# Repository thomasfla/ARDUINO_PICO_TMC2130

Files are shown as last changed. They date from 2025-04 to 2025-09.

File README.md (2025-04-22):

# ARDUINO_PICO_TMC2130
Control 3 TMC2130 stepper driver via USB comands (TMX2130 + RP2350 / RP2040)

This is configured to control stepper motors of a bambulab A1 mini.

## Hardware:

* 3x SilentStepStick - TMC2130 Stepper Motor Driver
* 1x Raspberry pi Pico2 dev board

## USB Protocol:

The board will be seen as a virtual COM port.

Send target position, max velocity and max acceleration for all axis (in step, step/s, step/s2)

`X 2000 1000 2000\n`
`Y 500 1000 2000\n` etc..

The driver will send at a chosen period the motor position and velocity:
`X 9030 0 Y 4340 0 Z 0 0`

You can update the target position on the fly. This is usefull for reactive control given other feedback inputs.

## Homing

The code includes a soft homing sequence that as been tuned for Bambulab A1 mini.
This uses stallGuard feature of the tmc2130 drivers.

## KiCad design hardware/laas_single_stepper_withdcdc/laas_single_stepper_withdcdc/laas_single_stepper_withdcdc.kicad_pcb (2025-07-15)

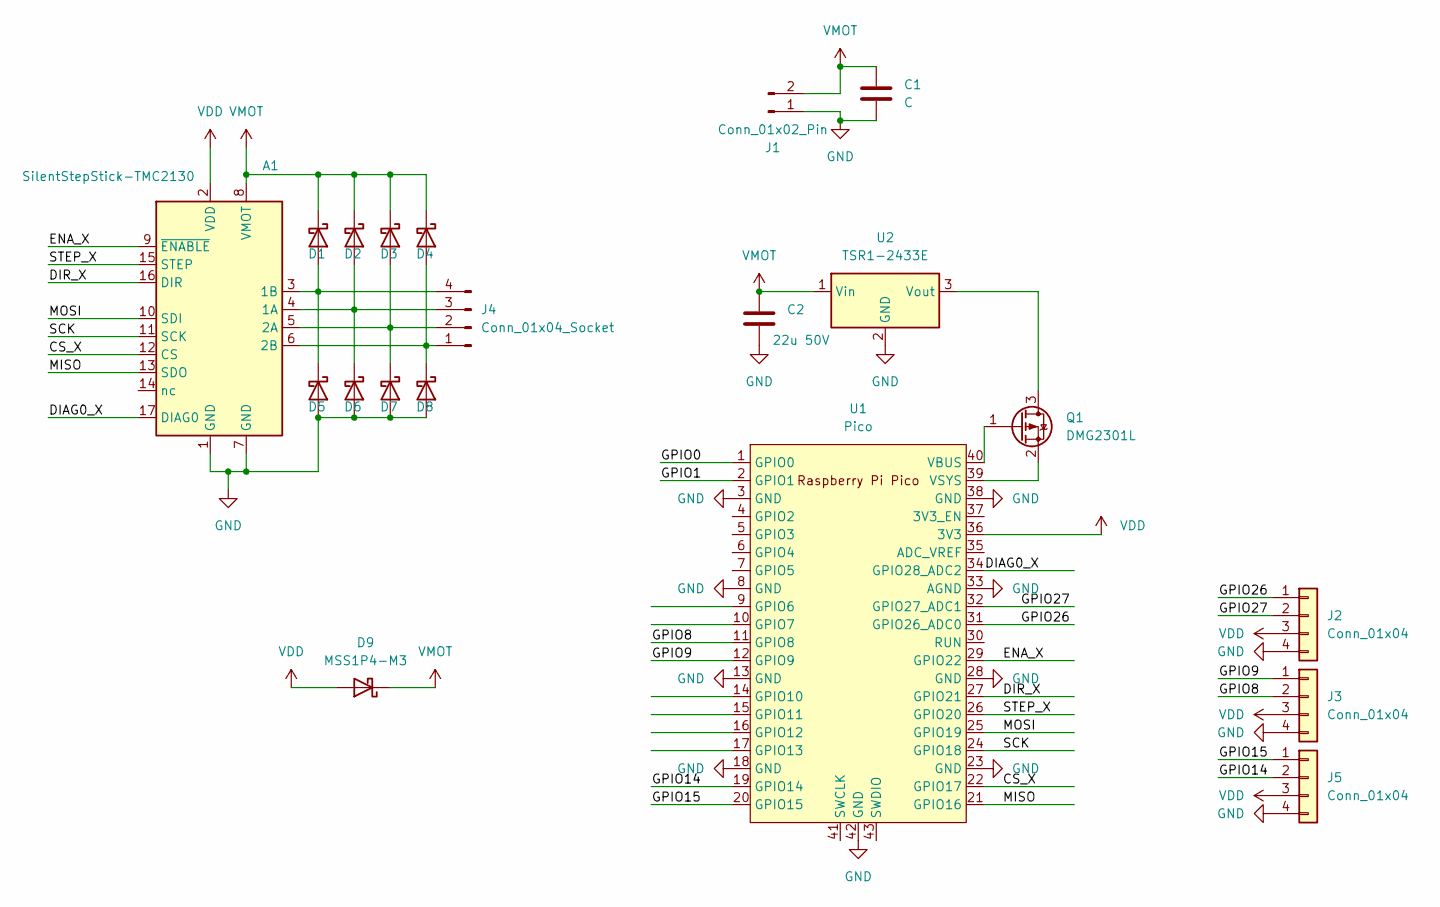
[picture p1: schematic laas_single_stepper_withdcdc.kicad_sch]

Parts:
A1: SilentStepStick-TMC2130; Pololu_Breakout-16_15.2x20.3mm
C1: C; C_1210_3225Metric
C2: 22u 50V; C_1210_3225Metric
D1, D2, D3, D4, D5, D6, D7, D8, D9: MSS1P4-M3; D_MicroSMP_AK
J1: Conn_01x02_Pin; AMASS_XT30PW-M_1x02_P2.50mm_Horizontal
J2, J3, J5: Conn_01x04; NS-Tech_Grove_1x04_P2mm_Vertical
J4: Conn_01x04_Socket; JST_XH_S4B-XH-A_1x04_P2.50mm_Horizontal
Q1: DMG2301L; SOT-23
U1: Pico; RPi_Pico_SMD_TH
U2: TSR1-2433E; Converter_DCDC_TRACO_TSR1-xxxxE_THT

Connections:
/CS_X: A1.12 (CS), U1.22 (GPIO17)
/DIAG0_X: A1.17 (DIAG0), U1.34 (GPIO28_ADC2)
/DIR_X: A1.16 (DIR), U1.27 (GPIO21)
/ENA_X: A1.9 (~ENABLE), U1.29 (GPIO22)
/GPIO0: U1.1 (GPIO0)
/GPIO1: U1.2 (GPIO1)
/GPIO8: J3.2, U1.11 (GPIO8)
/GPIO9: J3.1, U1.12 (GPIO9)
/GPIO14: J5.2, U1.19 (GPIO14)
/GPIO15: J5.1, U1.20 (GPIO15)
/GPIO26: J2.1, U1.31 (GPIO26_ADC0)
/GPIO27: J2.2, U1.32 (GPIO27_ADC1)
/MISO: A1.13 (SDO), U1.21 (GPIO16)
/MOSI: A1.10 (SDI), U1.25 (GPIO19)
/SCK: A1.11 (SCK), U1.24 (GPIO18)
/STEP_X: A1.15 (STEP), U1.26 (GPIO20)
GND: A1.1 (GND), A1.7 (GND), C1.2, C2.2, D5.2 (A), D6.2 (A), D7.2 (A), D8.2 (A), J1.1, J2.4, J3.4, J5.4, U1.3 (GND), U1.8 (GND), U1.13 (GND), U1.18 (GND), U1.23 (GND), U1.28 (GND), U1.33 (AGND), U1.38 (GND), U1.42 (GND), U2.2 (GND)
unnamed: A1.4 (1A), D2.2 (A), D6.1 (K), J4.3
unnamed: A1.3 (1B), D1.2 (A), D5.1 (K), J4.4
unnamed: A1.5 (2A), D3.2 (A), D7.1 (K), J4.2
unnamed: A1.6 (2B), D4.2 (A), D8.1 (K), J4.1
unnamed: Q1.3 (D), U2.3 (Vout)
unnamed: Q1.1 (G), U1.40 (VBUS)
unnamed: Q1.2 (S), U1.39 (VSYS)
VDD: A1.2 (VDD), D9.2 (A), J2.3, J3.3, J5.3, U1.36 (3V3)
VMOT: A1.8 (VMOT), C1.1, C2.1, D1.1 (K), D2.1 (K), D3.1 (K), D4.1 (K), D9.1 (K), J1.2, U2.1 (Vin)

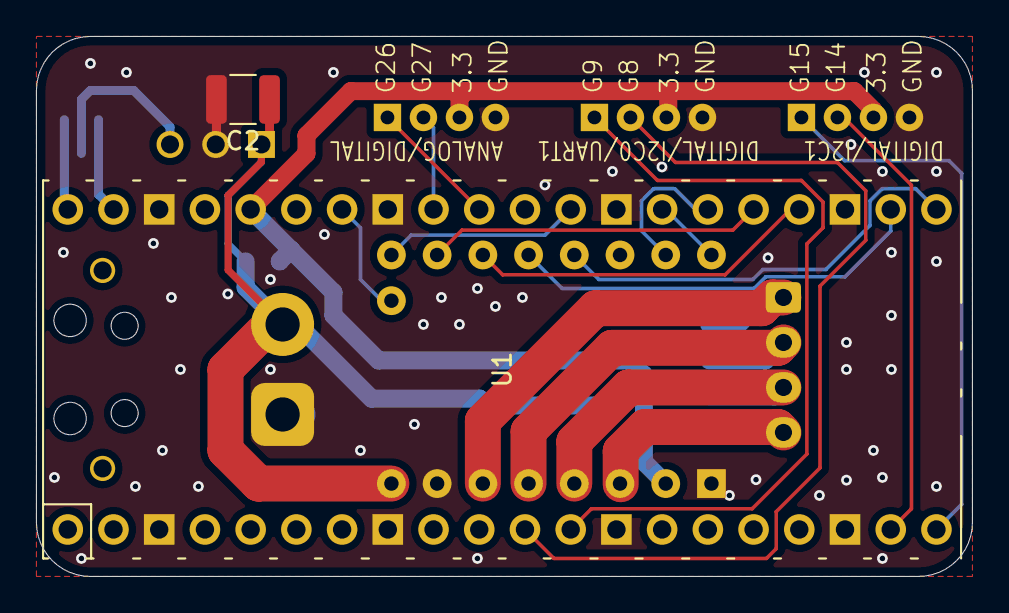
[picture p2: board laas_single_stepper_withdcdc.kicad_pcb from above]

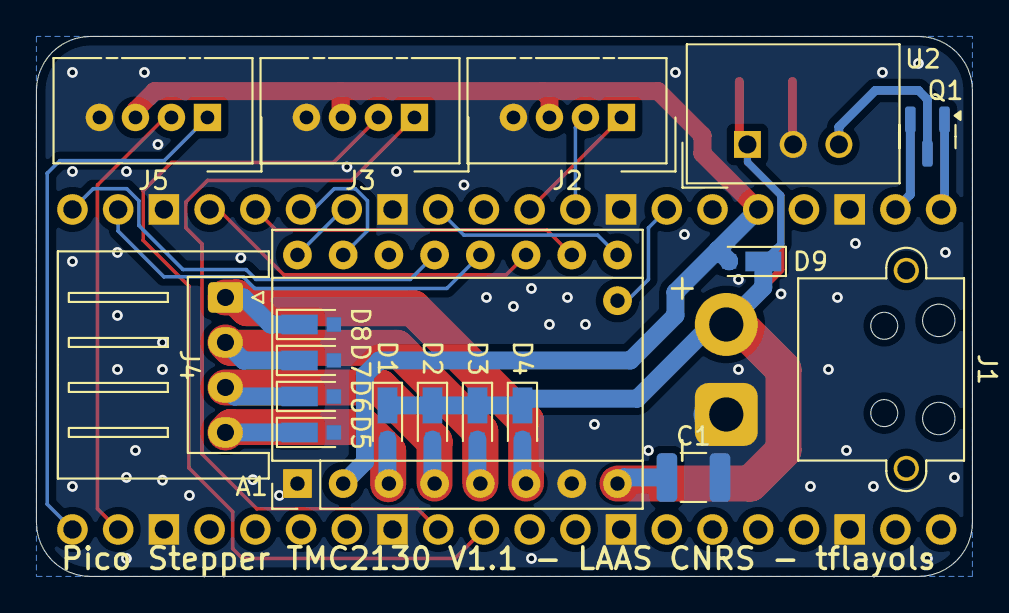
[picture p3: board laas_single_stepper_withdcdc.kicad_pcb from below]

Board: 2 copper layers, 52.0 x 30.0 mm, 20 parts (18 on the bottom side), 24 nets.

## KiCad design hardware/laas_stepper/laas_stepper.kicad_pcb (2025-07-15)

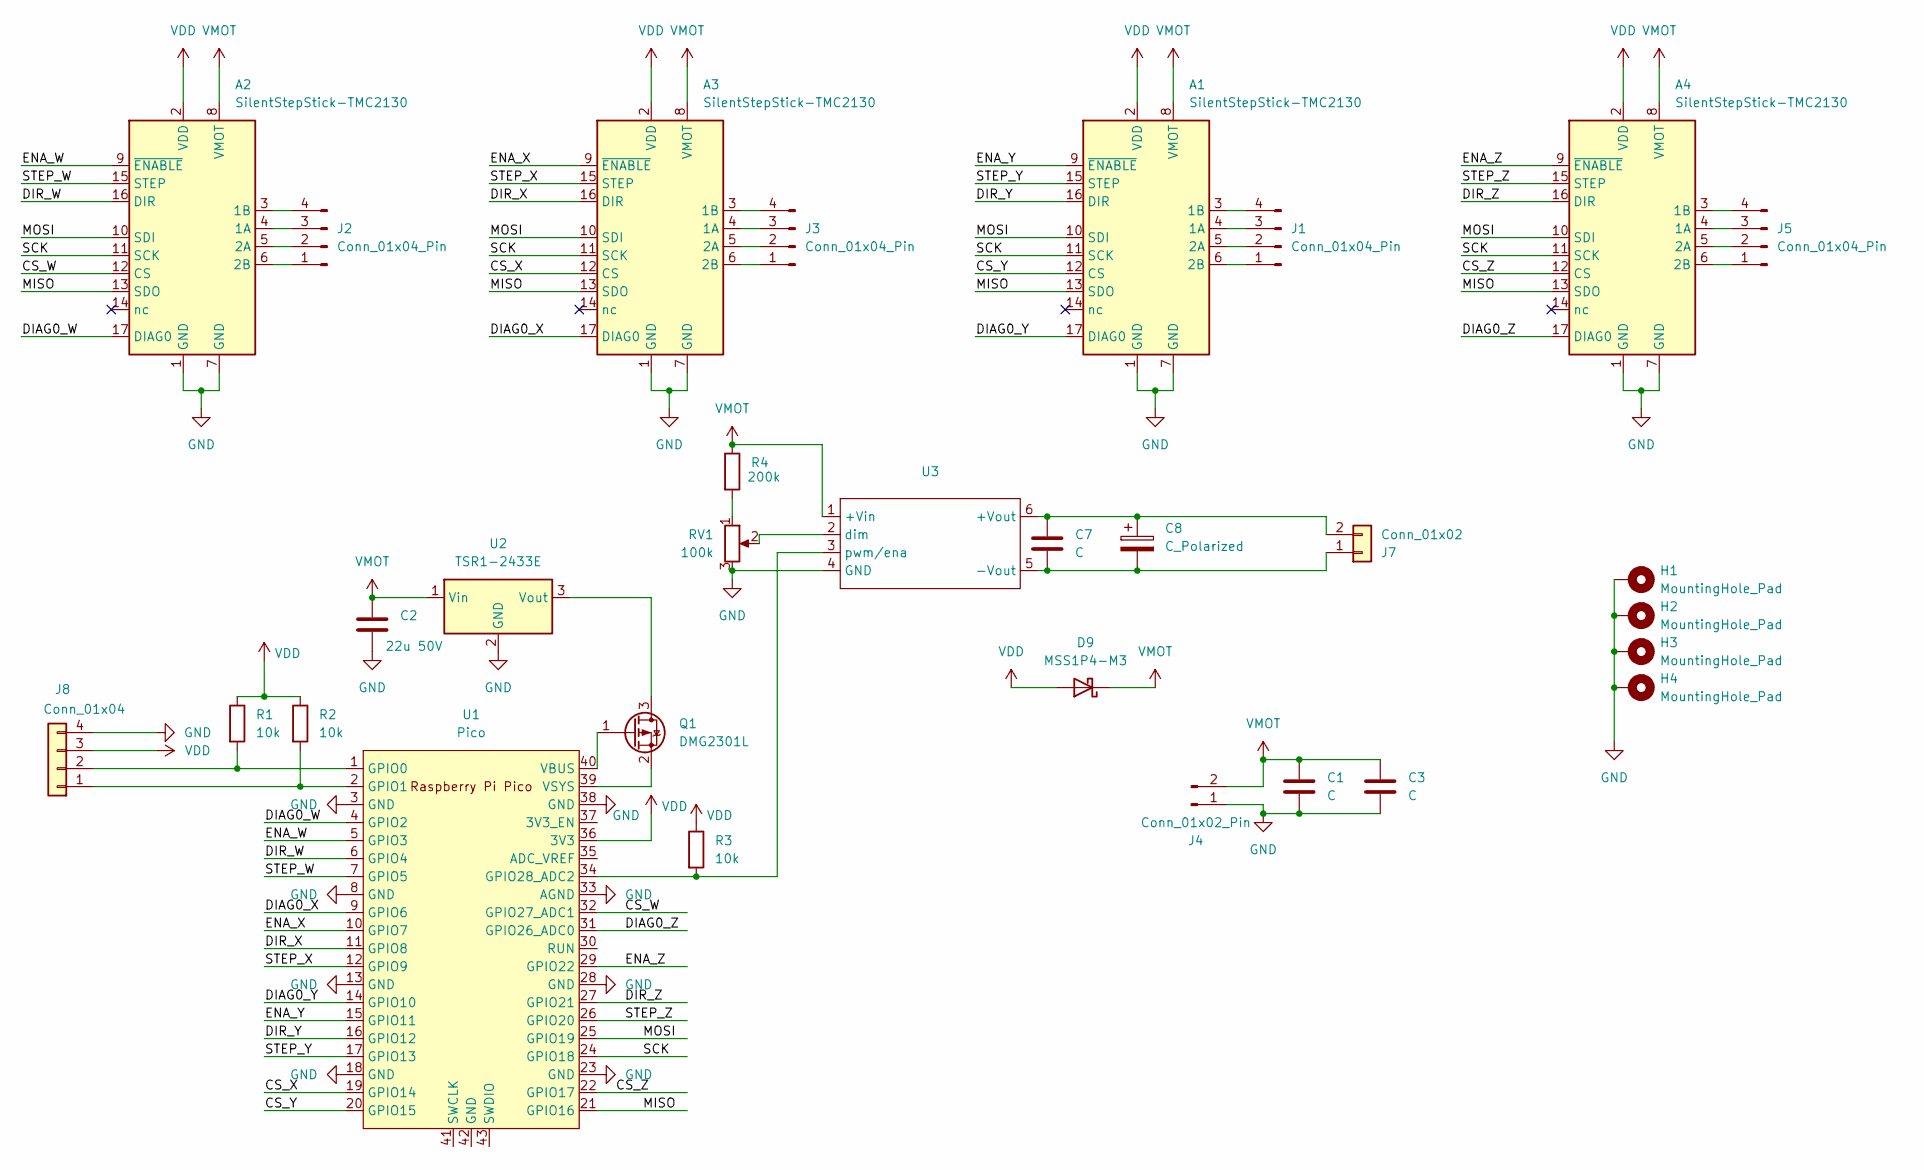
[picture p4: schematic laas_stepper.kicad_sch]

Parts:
A1, A2, A3, A4: SilentStepStick-TMC2130; Pololu_Breakout-16_15.2x20.3mm
C1, C3, C7: C; C_1210_3225Metric
C2: 22u 50V; C_1210_3225Metric
C8: C_Polarized; CP_Radial_D8.0mm_P3.80mm
D9: MSS1P4-M3; D_MicroSMP_AK
H1, H2, H3, H4: MountingHole_Pad; MountingHole_2.5mm_Pad_TopBottom
J1, J2, J3, J5: Conn_01x04_Pin; JST_XA_B04B-XASK-1_1x04_P2.50mm_Vertical
J4: Conn_01x02_Pin; AMASS_XT30PW-M_1x02_P2.50mm_Horizontal
J7: Conn_01x02; JST_XH_B2B-XH-A_1x02_P2.50mm_Vertical
J8: Conn_01x04; NS-Tech_Grove_1x04_P2mm_Vertical
Q1: DMG2301L; SOT-23
R1, R2, R3: 10k; R_0805_2012Metric
R4: 200k; R_0805_2012Metric
RV1: 100k; Potentiometer_Bourns_3296W_Vertical
U1: Pico; RaspberryPi_Pico_Common_Unspecified
U2: TSR1-2433E; Converter_DCDC_TRACO_TSR1-xxxxE_THT
U3: RCD-24_PL

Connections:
/CS_W: A2.12 (CS), U1.32 (GPIO27_ADC1)
/CS_X: A3.12 (CS), U1.19 (GPIO14)
/CS_Y: A1.12 (CS), U1.20 (GPIO15)
/CS_Z: A4.12 (CS), U1.22 (GPIO17)
/DIAG0_W: A2.17 (DIAG0), U1.4 (GPIO2)
/DIAG0_X: A3.17 (DIAG0), U1.9 (GPIO6)
/DIAG0_Y: A1.17 (DIAG0), U1.14 (GPIO10)
/DIAG0_Z: A4.17 (DIAG0), U1.31 (GPIO26_ADC0)
/DIR_W: A2.16 (DIR), U1.6 (GPIO4)
/DIR_X: A3.16 (DIR), U1.11 (GPIO8)
/DIR_Y: A1.16 (DIR), U1.16 (GPIO12)
/DIR_Z: A4.16 (DIR), U1.27 (GPIO21)
/ENA_W: A2.9 (~ENABLE), U1.5 (GPIO3)
/ENA_X: A3.9 (~ENABLE), U1.10 (GPIO7)
/ENA_Y: A1.9 (~ENABLE), U1.15 (GPIO11)
/ENA_Z: A4.9 (~ENABLE), U1.29 (GPIO22)
/MISO: A1.13 (SDO), A2.13 (SDO), A3.13 (SDO), A4.13 (SDO), U1.21 (GPIO16)
/MOSI: A1.10 (SDI), A2.10 (SDI), A3.10 (SDI), A4.10 (SDI), U1.25 (GPIO19)
/SCK: A1.11 (SCK), A2.11 (SCK), A3.11 (SCK), A4.11 (SCK), U1.24 (GPIO18)
/STEP_W: A2.15 (STEP), U1.7 (GPIO5)
/STEP_X: A3.15 (STEP), U1.12 (GPIO9)
/STEP_Y: A1.15 (STEP), U1.17 (GPIO13)
/STEP_Z: A4.15 (STEP), U1.26 (GPIO20)
GND: A1.1 (GND), A1.7 (GND), A2.1 (GND), A2.7 (GND), A3.1 (GND), A3.7 (GND), A4.1 (GND), A4.7 (GND), C1.2, C2.2, C3.2, H1.1, H2.1, H3.1, H4.1, J4.1, J8.4, RV1.3, U1.3 (GND), U1.8 (GND), U1.13 (GND), U1.18 (GND), U1.23 (GND), U1.28 (GND), U1.33 (AGND), U1.38 (GND), U2.2 (GND), U3.4 (GND)
unnamed: A1.4 (1A), J1.3
unnamed: A1.3 (1B), J1.4
unnamed: A1.5 (2A), J1.2
unnamed: A1.6 (2B), J1.1
unnamed: A2.4 (1A), J2.3
unnamed: A2.3 (1B), J2.4
unnamed: A2.5 (2A), J2.2
unnamed: A2.6 (2B), J2.1
unnamed: A3.4 (1A), J3.3
unnamed: A3.3 (1B), J3.4
unnamed: A3.5 (2A), J3.2
unnamed: A3.6 (2B), J3.1
unnamed: A4.4 (1A), J5.3
unnamed: A4.3 (1B), J5.4
unnamed: A4.5 (2A), J5.2
unnamed: A4.6 (2B), J5.1
unnamed: C7.2, C8.2, J7.1, U3.5 (-Vout)
unnamed: C7.1, C8.1, J7.2, U3.6 (+Vout)
unnamed: J8.1, R2.2, U1.2 (GPIO1)
unnamed: J8.2, R1.2, U1.1 (GPIO0)
unnamed: Q1.3 (D), U2.3 (Vout)
unnamed: Q1.1 (G), U1.40 (VBUS)
unnamed: Q1.2 (S), U1.39 (VSYS)
unnamed: R4.2, RV1.1
unnamed: R3.2, U1.34 (GPIO28_ADC2), U3.3 (pwm/ena)
unnamed: RV1.2, U3.2 (dim)
VDD: A1.2 (VDD), A2.2 (VDD), A3.2 (VDD), A4.2 (VDD), D9.2 (A), J8.3, R1.1, R2.1, R3.1, U1.36 (3V3)
VMOT: A1.8 (VMOT), A2.8 (VMOT), A3.8 (VMOT), A4.8 (VMOT), C1.1, C2.1, C3.1, D9.1 (K), J4.2, R4.1, U2.1 (Vin), U3.1 (+Vin)

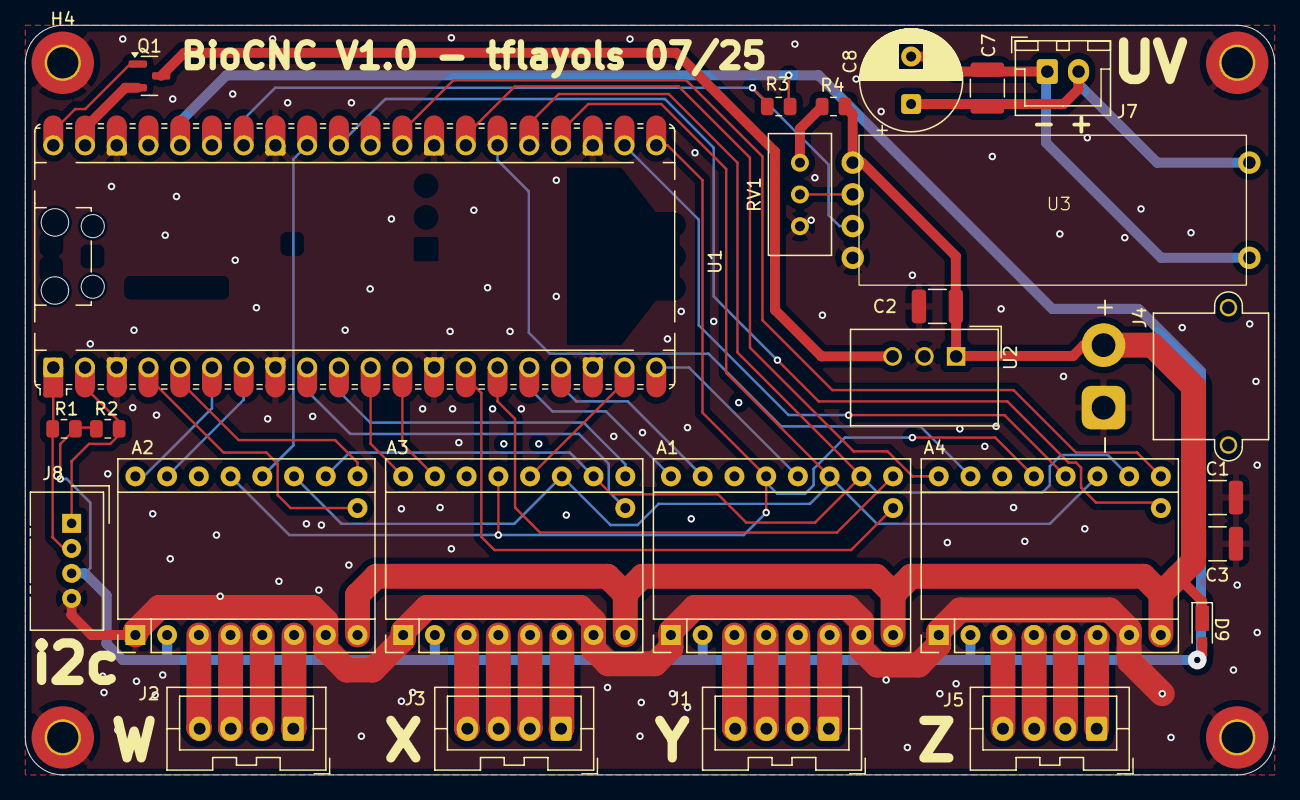
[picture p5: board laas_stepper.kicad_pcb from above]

Board: 2 copper layers, 100.0 x 60.0 mm, 30 parts (0 on the bottom side), 52 nets.

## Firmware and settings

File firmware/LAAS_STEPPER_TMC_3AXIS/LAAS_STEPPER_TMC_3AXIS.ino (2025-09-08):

/*
Thomas Flayols LAAS CNRS April 2025

Control stepper motor via TMC2130 drivers connected in SPI + Step/DIR
Receive simple commands via USB (emulated Serial)
Send back motor status every (FEEDBACK_PERIOD_MS) ms

Format:
    Commands "X 100 1000 5000\n" //Axis 'X' goto position 100 with max speed set to 1000 and max axeleration set to 5000
    State: "X 95 65 Y 0 0 Z 0 0\n" //X position is 95, velocity is 65. Y position is 0 etc...
*/
#include <TMCStepper.h>
#include <AccelStepper.h>

using namespace TMC2130_n;

// Software SPI pins
#define SW_MOSI 19
#define SW_MISO 16
#define SW_SCK  18

// Timing and hardware constants
#define FEEDBACK_PERIOD_MS 100
#define R_SENSE            0.11f

// Axis limits (steps, steps/s, steps/s^2)
#define X_MIN_POS_STEPS 0
#define X_MAX_POS_STEPS (17000)
#define X_MAX_VEL_STEPS (10000)
#define X_MAX_ACC_STEPS (200000)

#define Y_MIN_POS_STEPS 0
#define Y_MAX_POS_STEPS (15000)
#define Y_MAX_VEL_STEPS (10000)
#define Y_MAX_ACC_STEPS (200000)

#define Z_MIN_POS_STEPS 0
#define Z_MAX_POS_STEPS (72000)
#define Z_MAX_VEL_STEPS (5000)
#define Z_MAX_ACC_STEPS (100000)



/*
// Axis-specific pin and parameter defines
// X axis
#define X_CS_PIN      17
#define X_EN_PIN      22
#define X_DIR_PIN     21
#define X_STEP_PIN    20
#define X_DIAG0_PIN    5 //2
#define X_MICROSTEPS  16
#define X_CURRENT_MA 500
#define X_STALL_VALUE  3

// Y axis
#define Y_CS_PIN       6
#define Y_EN_PIN       7
#define Y_DIR_PIN      8
#define Y_STEP_PIN     9
#define Y_DIAG0_PIN    3
#define Y_MICROSTEPS   16
#define Y_CURRENT_MA 500
#define Y_STALL_VALUE  3

// Z axis
#define Z_CS_PIN      10
#define Z_EN_PIN      11
#define Z_DIR_PIN     12
#define Z_STEP_PIN    13
#define Z_DIAG0_PIN    4
#define Z_MICROSTEPS   16
#define Z_CURRENT_MA 500
#define Z_STALL_VALUE 13
*/


// Axis-specific pin and parameter defines
// X axis
#define X_CS_PIN      14
#define X_EN_PIN       7
#define X_DIR_PIN      8
#define X_STEP_PIN     9
#define X_DIAG0_PIN    6 //2
#define X_MICROSTEPS  16
#define X_CURRENT_MA 500
#define X_STALL_VALUE  3

// Y axis
#define Y_CS_PIN       15
#define Y_EN_PIN       11
#define Y_DIR_PIN      12
#define Y_STEP_PIN     13
#define Y_DIAG0_PIN    10
#define Y_MICROSTEPS   16
#define Y_CURRENT_MA 500
#define Y_STALL_VALUE  3

// Z axis
#define Z_CS_PIN      17
#define Z_EN_PIN      22
#define Z_DIR_PIN     21
#define Z_STEP_PIN    20
#define Z_DIAG0_PIN    26
#define Z_MICROSTEPS   16
#define Z_CURRENT_MA 500
#define Z_STALL_VALUE 13

#define UV_EN_PIN 28

// Axis configuration struct
typedef struct {
    char     name;          // Axis identifier
    uint8_t  cs;            // Chip select pin
    uint8_t  en;            // Enable pin
    uint8_t  dir;           // Direction pin
    uint8_t  step;          // Step pin
    int8_t   diag0;         // StallGuard / homing pin (-1 if unused)
    uint32_t microsteps;    // Microstep setting
    uint16_t current_mA;    // RMS current setting
    int16_t stall_value;    // StallGuard threshold
    int32_t  min_pos;       // Minimum position (steps)
    int32_t  max_pos;       // Maximum position (steps)
    uint32_t max_vel;       // Maximum velocity (steps/s)
    uint32_t max_acc;       // Maximum acceleration (steps/s^2)
} AxisConfig;

// Runtime data for each axis
typedef struct {
    TMC2130Stepper *driver;
    AccelStepper   *stepper;
} AxisData;

// Global driver instances (accessible from core 2)
TMC2130Stepper driverX(X_CS_PIN, R_SENSE, SW_MOSI, SW_MISO, SW_SCK);
TMC2130Stepper driverY(Y_CS_PIN, R_SENSE, SW_MOSI, SW_MISO, SW_SCK);
TMC2130Stepper driverZ(Z_CS_PIN, R_SENSE, SW_MOSI, SW_MISO, SW_SCK);

// Global stepper instances (accessible from core 2)
AccelStepper stepperX(AccelStepper::DRIVER, X_STEP_PIN, X_DIR_PIN);
AccelStepper stepperY(AccelStepper::DRIVER, Y_STEP_PIN, Y_DIR_PIN);
AccelStepper stepperZ(AccelStepper::DRIVER, Z_STEP_PIN, Z_DIR_PIN);

// Axis configurations using defined constants
AxisConfig axisConfigs[] = {
    { 'X', X_CS_PIN, X_EN_PIN, X_DIR_PIN, X_STEP_PIN, X_DIAG0_PIN, X_MICROSTEPS, X_CURRENT_MA, X_STALL_VALUE, X_MIN_POS_STEPS, X_MAX_POS_STEPS, X_MAX_VEL_STEPS, X_MAX_ACC_STEPS },
    { 'Y', Y_CS_PIN, Y_EN_PIN, Y_DIR_PIN, Y_STEP_PIN, Y_DIAG0_PIN, Y_MICROSTEPS, Y_CURRENT_MA, Y_STALL_VALUE, Y_MIN_POS_STEPS, Y_MAX_POS_STEPS, Y_MAX_VEL_STEPS, Y_MAX_ACC_STEPS },
    { 'Z', Z_CS_PIN, Z_EN_PIN, Z_DIR_PIN, Z_STEP_PIN, Z_DIAG0_PIN, Z_MICROSTEPS, Z_CURRENT_MA, Z_STALL_VALUE, Z_MIN_POS_STEPS, Z_MAX_POS_STEPS, Z_MAX_VEL_STEPS, Z_MAX_ACC_STEPS }
};
AxisData axes[3];

unsigned long lastFeedback = 0;

// Initialize hardware for one axis
void axis_init(int idx) {
    AxisConfig *cfg = &axisConfigs[idx];
    pinMode(cfg->cs, OUTPUT);
    digitalWrite(cfg->cs, HIGH);
    pinMode(cfg->en, OUTPUT);
    digitalWrite(cfg->en, LOW);
    if (cfg->diag0 >= 0) pinMode(cfg->diag0, INPUT);

    // Assign global driver and configure
    TMC2130Stepper *drv = (idx == 0 ? &driverX : idx == 1 ? &driverY : &driverZ);
    axes[idx].driver = drv;
    drv->begin();
    drv->rms_current(cfg->current_mA);
    drv->microsteps(cfg->microsteps);
    drv->en_pwm_mode(true);
    drv->pwm_autoscale(true);
    if (cfg->diag0 >= 0) {
        drv->sgt(cfg->stall_value);
        drv->diag0_stall(true);
        drv->diag0_int_pushpull(true);
    }

    // Assign global stepper and configure
    AccelStepper *stp = (idx == 0 ? &stepperX : idx == 1 ? &stepperY : &stepperZ);
    axes[idx].stepper = stp;
    stp->setEnablePin(cfg->en);
    stp->setPinsInverted(true, false, true);
    stp->enableOutputs();
    stp->setMaxSpeed(cfg->max_vel);
    stp->setAcceleration(cfg->max_acc);
}

// Perform homing for an axis (only X by default)
void axis_home(int idx, bool direction = 0, int home_position = 0) {
    AxisConfig *cfg = &axisConfigs[idx];
    if (cfg->diag0 < 0) return;
    TMC2130Stepper *drv = axes[idx].driver;
    AccelStepper   *stp = axes[idx].stepper;

    drv->en_pwm_mode(false);
    drv->pwm_autoscale(false);
    drv->TCOOLTHRS(0xFFFFF); // 20bit max
    drv->THIGH(0);
    delay(100);
    digitalWrite(cfg->dir, direction);
    tone(cfg->step, 2000);
    delay(100);
    while (!gpio_get(cfg->diag0)); //Time critical, todo disable interupt? move this check to a PIO program?
    noTone(cfg->step);
    drv->TCOOLTHRS(0);
    drv->en_pwm_mode(true);
    drv->pwm_autoscale(true);
    stp->setCurrentPosition(home_position);
}

// Set motion parameters and target
void axis_setMotion(int idx, int32_t pos, uint32_t vel, uint32_t acc) {
    AxisConfig *cfg = &axisConfigs[idx];
    AccelStepper *stp = axes[idx].stepper;

    // Clamp position, velocity, and acceleration to allowed range
    if (pos < cfg->min_pos) pos = cfg->min_pos;
    if (pos > cfg->max_pos) pos = cfg->max_pos;
    if (vel > cfg->max_vel) vel = cfg->max_vel;
    if (acc > cfg->max_acc) acc = cfg->max_acc;

    stp->setMaxSpeed(vel);
    stp->setAcceleration(acc);
    stp->moveTo(pos);
}

void setup() {
    analogWriteFreq(1000);
    Serial.begin(9600);
    while (!Serial);

    pinMode(UV_EN_PIN,OUTPUT);
    digitalWrite(UV_EN_PIN, 1);

    SPI.begin();

    axis_init(0);
    axis_home(0,1);

    axis_init(1);
    axis_home(1,1);

    axis_init(2);
    axis_home(2,0,72000);
    //demo();
}

void demo()
{

    int z = 20000;
    int i=0;
    axes[0].stepper->runToNewPosition(15000);
    axes[1].stepper->runToNewPosition(1000);
    axes[2].stepper->runToNewPosition(z);
    while(1)
    {
        axes[0].stepper->runToNewPosition(15000);
        for(i=0;i<5;i++)
        {
            axes[1].stepper->runToNewPosition(1000);
            axes[2].stepper->runToNewPosition(z-1000);
            axes[2].stepper->runToNewPosition(z);
            axes[1].stepper->runToNewPosition(2000);
            axes[2].stepper->runToNewPosition(z-1000);
            axes[2].stepper->runToNewPosition(z);
        }
        axes[0].stepper->runToNewPosition(1000);
        for(i=0;i<2;i++)
        {
            axes[1].stepper->runToNewPosition(1000);
            axes[2].stepper->runToNewPosition(z-1000);
            axes[2].stepper->runToNewPosition(z);
            axes[1].stepper->runToNewPosition(5000);
            axes[2].stepper->runToNewPosition(z-1000);
            axes[2].stepper->runToNewPosition(z);
        }
    } 
}



void loop() {
    // Command handling
    if (Serial.available()) {
        String cmd = Serial.readStringUntil('\n');
        char axis; uint32_t arg1, arg2, arg3;
        if (sscanf(cmd.c_str(), "%c %lu %lu %lu", &axis, &arg1, &arg2, &arg3) == 4) {
            for (int i = 0; i < 3; ++i) {
                if (axisConfigs[i].name == axis) {
                    axis_setMotion(i, arg1, arg2, arg3);
                    break;
                }
            }
        }
        else if((sscanf(cmd.c_str(), "%c %lu", &axis, &arg1) == 2)){
            if(axis=='U')
            {
                analogWrite(UV_EN_PIN,arg1) ;
                //if(arg1==1) analogWrite(UV_EN_PIN,arg1) ;//digitalWrite(UV_EN_PIN, 0);
                //if(arg1==0) ;//digitalWrite(UV_EN_PIN, 1);
            }            
        }
    }


    // Update steppers directly
    axes[0].stepper->run();
    axes[1].stepper->run();
    axes[2].stepper->run();

    // Periodic feedback inline
    if (millis() - lastFeedback >= FEEDBACK_PERIOD_MS) {
        lastFeedback = millis();
        Serial.printf(
            "X %ld %f Y %ld %f Z %ld %f\n",
            axes[0].stepper->currentPosition(), axes[0].stepper->speed(),
            axes[1].stepper->currentPosition(), axes[1].stepper->speed(),
            axes[2].stepper->currentPosition(), axes[2].stepper->speed()
        );
    }
}

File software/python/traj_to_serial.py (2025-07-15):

#!/usr/bin/env python3
import serial
import time

def gotoX(ser, x, vel=4000, acc=20000):
	message = f"X {x} {vel} {acc}\n"
	ser.write(message.encode('utf-8'))


def main():
    # Update the port name and baud rate for your setup.
    port = "/dev/ttyACM0"  
    baud_rate = 115200
    try:
        ser = serial.Serial(port, baud_rate, timeout=1)
        print(f"Opened serial port {port} at {baud_rate} baud.")
    except serial.SerialException as e:
        print(f"Error opening serial port {port}: {e}")
        return


    for i in range (10):
        gotoX(ser,5000)
        
        time.sleep(2)
        gotoX(ser,0)
        time.sleep(2)
        print (i)


if __name__ == "__main__":
    main()

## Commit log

2025-04-29 update PCB
    [laas_single_stepper.kicad_sch]
2025-07-15 4 axis version, with UV LED controller + GROVE connector; nex single axis with DC DC to make usb power optional, with GROVE connectors
    [laas_single_stepper_withdcdc.kicad_pcb, laas_single_stepper_withdcdc.kicad_sch, laas_stepper.kicad_pcb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]
2025-09-08 Adapt firmware to custom board.
    [laas_stepper.kicad_sch]
